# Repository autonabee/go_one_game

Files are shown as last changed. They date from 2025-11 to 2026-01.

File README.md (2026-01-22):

# Description

Go One Game est un projet de manette à une main. Ce repo contient les fichiers et ressources utiles pour réaliser une manette Go One Game.

# Aperçu des fichiers

- `conception3D` : dossier contenant les fichiers .stl pour imprimer la coque de la manette.
- `hardware` : dossier contenant le schéma des branchements et le code Arduino de la manette. 

# Dossier `conception3D`

## V2
Ce dossier contient les fichiers .stl du prototype v2 :
- `BaseV2.stl` : base arrondie avec trous pour vis de diamètre 2,5 mm. Espace pour poser l'Arduino, les résistances et le gyroscope.
- `CoqueV2.stl` : coque avec espace pour le joystick et les boutons.
La base et la coque ont un système d'attache par emboîtement de 3 cylindres, dans lesquels on peut visser (trous sous la base).

## V3
Ce dossier contient les fichiers .stl du prototype v3 :
- `BaseV3.stl` : base arrondie avec trous pour vis de diamètre 2,5 mm. Espace pour poser l'Arduino, les résistances et le gyroscope.
- `CoqueV3.stl` : coque avec espace pour le joystick et les boutons. 3 espaces pour des écrous de diamètre 2,5 mm.
Améliorations par rapport à la v2 :
- La manette v3 a un système de fermeture par vis et écrous plus efficace
- La v3 est 10% plus grande pour permettre plus d'espace pour les composants

# Dossier `hardware`

Le fichier `GoOneGame_main.ino`contient le code pour le prototype v2 de la manette Go One Game, qui comprend 2 joysticks (1 classique et 1 par gyroscope), les 4 boutons d'action ABXY, les 2 boutons LB et RB, les 2 gâchettes LT et RT (remplacées par des boutons poussoirs et donc non-analogique).  
L'Arduino se comporte comme une manette Xbox.

Matériel utilisé (voir `Schema_electronique.pdf` pour le branchement):

- Arduino Micro
- Module gyroscope-accéléromètre MPU6050
- Joystick
- 8 résistances 10 kOhm
- 8+1 boutons poussoirs

NB : Changer les valeurs des angles limites du gyroscope pour s'adapter à l'amplitude des mouvements possibles.

```cpp
int upperLimit = 45; // 10 est une bonne valeur
int lowerLimit = -45; 
```

## Prérequis

### __Arduino XInput Library__

<https://github.com/dmadison/ArduinoXInput>

Prérequis : <https://github.com/dmadison/ArduinoXInput_AVR?tab=readme-ov-file>

Utiliser la carte Arduino comme Xbox

### __Arduino MPU6050_tockn Library__

<https://github.com/tockn/MPU6050_tockn>

Librairie pour utiliser le gyroscope MPU6050

## Tutoriels utiles

### __DIY MPU-6050 USB Joystick__

<https://www.instructables.com/DIY-MPU-6050-USB-Joystick/>

Tutoriel et code pour utiliser un gyroscope MPU6050 comme joystick

Prérequis : librairie MPU6050_tockn, librairie Joystick de MHeironimus

A adapter pour utiliser avec XInput plutôt que Joystick

### __How to Emulate an Xbox Controller with Arduino (XInput)__

<https://www.partsnotincluded.com/how-to-emulate-an-xbox-controller-with-arduino-xinput/>

Tutoriel pour installer et utiliser la librairie XInput

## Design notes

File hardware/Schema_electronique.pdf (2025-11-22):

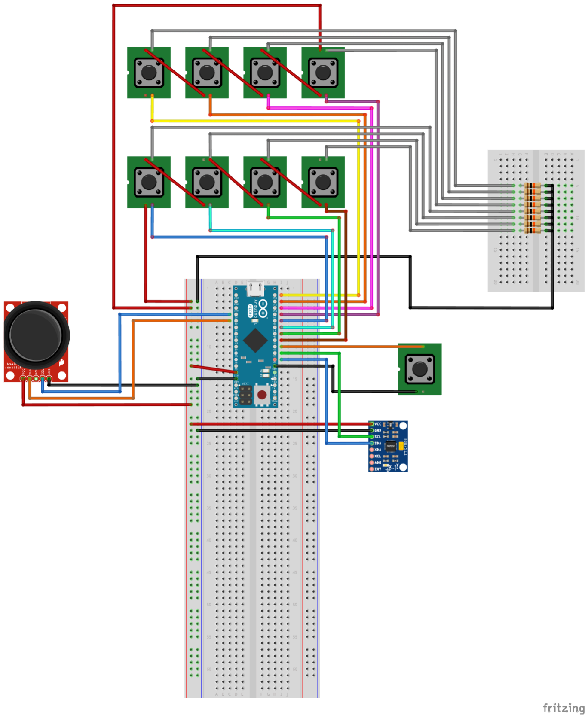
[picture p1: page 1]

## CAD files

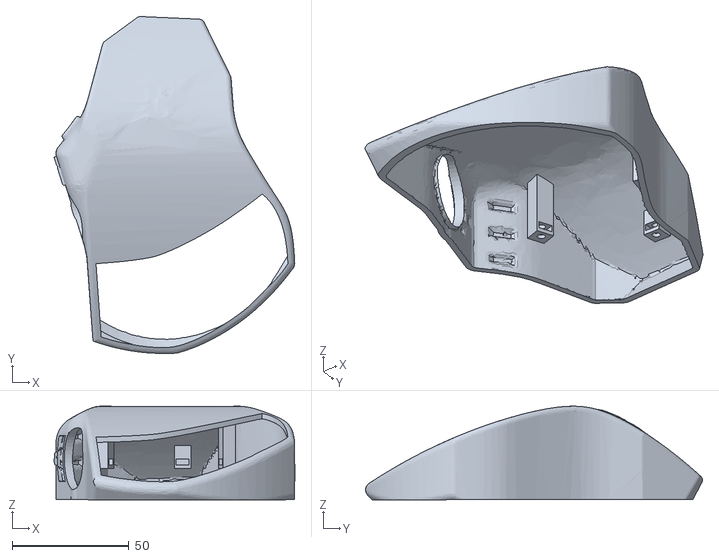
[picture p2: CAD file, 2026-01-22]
conception3D/V3/CoqueV3.stl
103.1 x 144.4 x 40.2

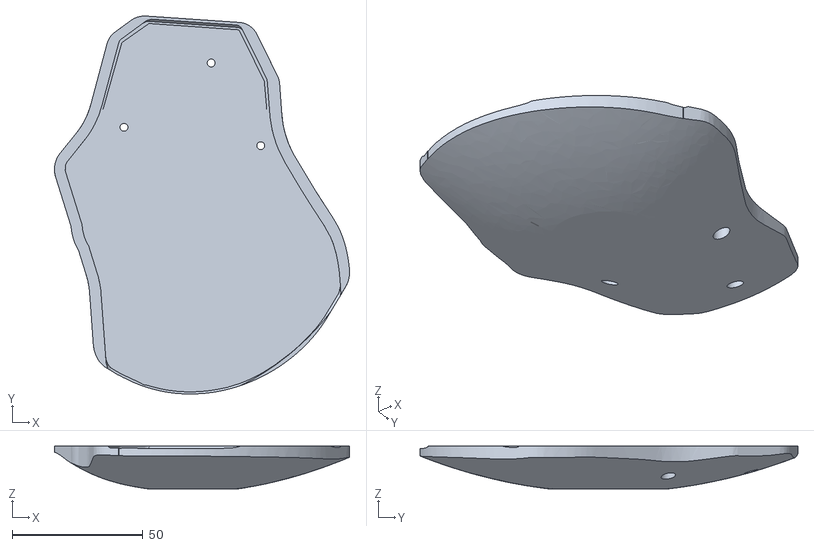
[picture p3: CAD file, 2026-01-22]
conception3D/V3/BaseV3.stl
112.7 x 144.4 x 16.4

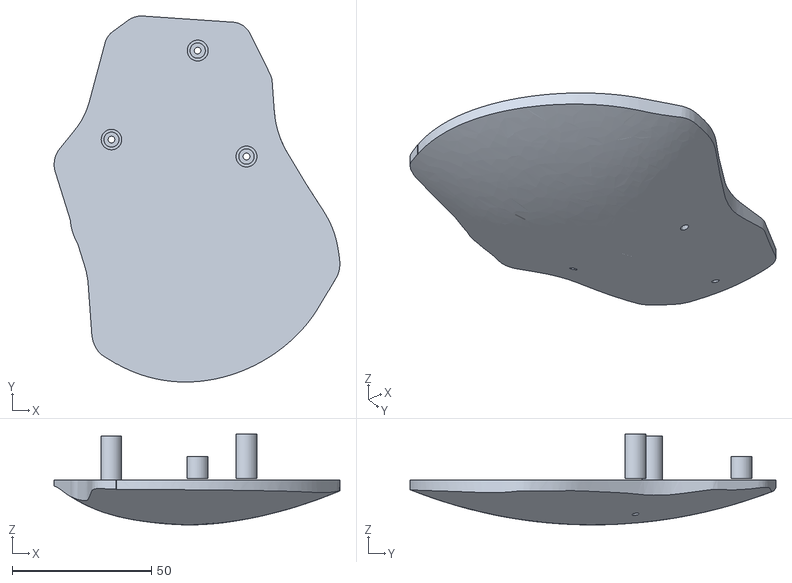
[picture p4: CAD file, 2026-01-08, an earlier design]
conception3D/V2/BaseV2.stl
102.5 x 131.3 x 32.6

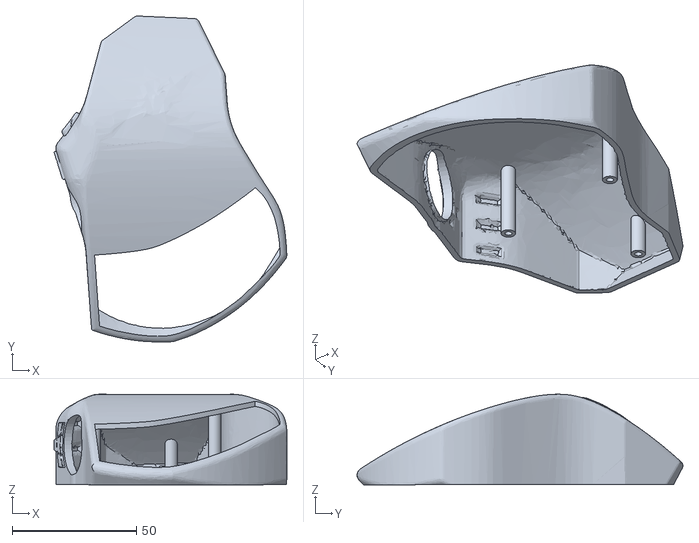
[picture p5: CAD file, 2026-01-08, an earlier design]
conception3D/V2/CoqueV2.stl
93.7 x 131.3 x 36.5

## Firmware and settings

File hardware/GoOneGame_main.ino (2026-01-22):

#include <XInput.h>
#include <MPU6050_tockn.h>
#include <Wire.h>

MPU6050 mpu6050(Wire);

// Joystick
#define JOY1_X A0
#define JOY1_Y A1

// Bouton pour reset la position du gyroscope
#define RESET_JOY 4 

// Boutons d'actions
// Config 1 en ligne
// #define BUTT_A 12
// #define BUTT_B 11
// #define BUTT_X 10
// #define BUTT_Y 9
// #define BUTT_RT 8 
// #define BUTT_LT 7
// #define BUTT_RB 6
// #define BUTT_LB 5 

// Config 2
#define BUTT_A 7
#define BUTT_B 8
#define BUTT_X 11
#define BUTT_Y 12
#define BUTT_RT 6
#define BUTT_LT 5
#define BUTT_RB 10
#define BUTT_LB 9


float joyZeroX=0;
float joyZeroY=0;

// limite inf et sup de l'angle (en degrés) détecté par le gyroscope
int upperLimit = 20; 
int lowerLimit = -20; 

void setup() {
  pinMode(BUTT_A, INPUT);
  pinMode(BUTT_B, INPUT);
  pinMode(BUTT_X, INPUT);
  pinMode(BUTT_Y, INPUT);
  pinMode(BUTT_LT, INPUT);
  pinMode(BUTT_RT, INPUT);
  pinMode(BUTT_LB, INPUT);
  pinMode(BUTT_RB, INPUT);

  pinMode(RESET_JOY, INPUT_PULLUP);

  Wire.begin();
  mpu6050.begin();

  //XInput.setAutoSend(false);  // Wait for all controls before sending
  XInput.begin();
}


void ResetMPU6050(float x, float y){
  // Définit l'origine du gyroscope à la position actuelle
  joyZeroX=x;
  joyZeroY=y;
}


void loop() {
  // JOYSTICK
  XInput.setJoystickY(JOY_RIGHT, map(analogRead(JOY1_X), 0, 1023, -32767, 32767)); // Modifier axes X/Y et mapping des valeurs pour adapter à l'orientation du joystick
  XInput.setJoystickX(JOY_RIGHT, map(analogRead(JOY1_Y), 0, 1023, -32767, 32767));

  // BOUTONS
  XInput.setButton(BUTTON_A, digitalRead(BUTT_A));
  XInput.setButton(BUTTON_B, digitalRead(BUTT_B));
  XInput.setButton(BUTTON_X, digitalRead(BUTT_X)); 
  XInput.setButton(BUTTON_Y, digitalRead(BUTT_Y));

  XInput.setButton(BUTTON_LB, digitalRead(BUTT_LB));
  XInput.setButton(BUTTON_RB, digitalRead(BUTT_RB));

  // GACHETTES
  XInput.setTrigger(TRIGGER_LEFT, map(digitalRead(BUTT_LT),0,1,0,255)); // Des boutons servent de gâchettes. Si le bouton est appuyé (1), la gâchette est entièrement appuyée (255)
  XInput.setTrigger(TRIGGER_RIGHT, map(digitalRead(BUTT_RT),0,1,0,255));


  // GYRO - JOYSTICK
  mpu6050.update();
  float joy2Y=mpu6050.getAngleX(); // float joy2Y=mpu6050.getAngleY(); // selon l'orientation du gyroscope dans la manette
  float joy2X=mpu6050.getAngleY(); // float joy2X=mpu6050.getAngleX();
  if (!digitalRead(RESET_JOY)) { // si le bouton RESET est appuyé
    ResetMPU6050(joy2X,joy2Y); // la position actuelle est définie comme origine du joystick
    }
  joy2X -= joyZeroX; // valeur par rapport à l'origine définie par l'utilisateur
  joy2Y -= joyZeroY;
  
  if (joy2X>upperLimit) joy2X=upperLimit; // angles bornés à la limite définie auparavant
  else if (joy2X<lowerLimit) joy2X=lowerLimit;
  if (joy2Y>upperLimit) joy2Y=upperLimit;
  else if (joy2Y<lowerLimit) joy2Y=lowerLimit;
 
  XInput.setJoystickX(JOY_LEFT, map(joy2X, lowerLimit,upperLimit, -32767, 32767)); // -32767, 32767 selon l'orientation du gyroscope dans la manette
  XInput.setJoystickY(JOY_LEFT, map(joy2Y, lowerLimit,upperLimit, 32767, -32767)); // idem

  XInput.send(); // envoi nouveau paquet à l'ordinateur
}

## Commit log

2026-01-08 Ajout des fichiers .stl de la v2 et maj du readme
    [BaseV2.stl, CoqueV2.stl]
2026-01-22 Ajout fichiers 3D V3
    [BaseV3.stl, CoqueV3.stl]
